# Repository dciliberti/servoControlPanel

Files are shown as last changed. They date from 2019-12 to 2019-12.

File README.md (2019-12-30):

# servoControlPanel
A panel to control a servo rotation and read angle on a LCD display, with the possibility to set a reference angle and read values from that reference. Useful to get the deflection angle of a control surface from a datum. Once set a reference angle, to get again the absolute position of the servo, just reset the Arduino. There is also the possibility to perform an automatic sweep between two given angles, from a given reference, and to change the rotational speed of the servo, by adjusting the delay between successive angles.

## Task
The idea is to realize an instrument panel to control a servo and display the angle and sweep mode on a LCD screen. Although compact and cheap boards dedicated to servo testing do exist, I wanted to realize a device to control and display the flap deflection of a wing model in a little, didactic wind tunnel and I wanted to do it, as far as possible, with the items provided in the [Arduino Starter Kit](https://store.arduino.cc/genuino-starter-kit).

## Requirements
Usually, servo testers give the possibility to control the servo angle by rotating a knob, put the servo in the neutral position, and sweep automatically between the minimum and maximum angle positions. Since my objective is to provide a user interface for wing angle of attack variation or control surface deflection, I do not need to put the servo in the neutral position (i.e. 90° if the servo rotates between 0° and 180°), but I need a switch to set a reference zero angle. In fact, the servo may be at any position while the wing (or control surface) angle relative to the wind is null. Also, I am interested to measure the deflection of the control surface relative to the reference zero. Finally, I want the servo to automatically sweep between two given angles around the reference zero at a certain angular velocity, which I want to control, although I am not interested in measuring it (I just want it to rotate faster or slower).

## Usage
The panel operates in two modes: manual control and auto sweep. The user interface provides three buttons, a knob, and a LCD screen. The display shows the servo angle in manual control mode and the limit angles (set in the Arduino code and not editable from the panel) in auto- sweep mode. The switch buttons serve as zeroing the reference angle, commuting between the manual control and auto-sweep mode, and changes the sign of the angle reported on the LCD display. In fact, since the servo rotation may be opposite to the desired convention, the last switch button gives the possibility to change the sign on the screen, but does not invert the rotation of the servo, which is linked to the rotation of the knob. In manual control mode, the servo knob controls the servo angle, which is shown on the LCD screen. Initially, the display shows the servo absolute angle, after the zeroing it shows the servo angle relative to that zero. In the auto-sweep mode, the servo knob controls the rotation rate by adjusting the delay between consecutive rotations (between 15 and 100 ms). By default, the auto-sweep mode rotates the servo in the range -30° to +60° from the reference zero value. The program limits the servo rotation if the reference zero plus the sweep range run out of the limits (0-179).

## Final considerations
I have managed to use items from the Arduino Starter Kit except for the bigger breadboard. Consider that you may need an external power source to control the servo, according to the voltage and power consumption of your device. If the servo vibrates, check your connections, then try to add an external power source. You may need to rearrange some of the items on your breadboard with respect to what is shown on my pictures. Additional information and pictures are available in the [docs folder](docs/).

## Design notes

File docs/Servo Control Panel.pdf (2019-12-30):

## Servo Control Panel

The idea is to realize an instrument panel to control a servo and display the angle and sweep mode on a LCD screen. Although compact and cheap boards dedicated to servo testing do exist, I wanted to realize a device to control and display the flap deflection of a wing model in a little, didactic wind tunnel and I wanted to do it, as far as possible, with the items provided in the Arduino Starter Kit. Usually, servo testers give the possibility to control the servo angle by rotating a knob, put the servo in the neutral position, and sweep automatically between the minimum and maximum angle positions. Since my objective is to provide a user interface for wing angle of attack variation or control surface deflection (Fig. 1), I do not need to put the servo in the neutral position (i.e. 90° if the servo rotates between 0° and 180°), but I need a switch to set a reference zero angle. In fact, the servo may be at any position while the wing (or control surface) angle relative to the wind is null. Also, I am interested to measure the deflection of the control surface relative to the reference zero. Finally, I want the servo to automatically sweep between two given angles around the reference zero at a certain angular velocity, which I want to control, although I am not interested in measuring it (I just want it to rotate faster or slower).

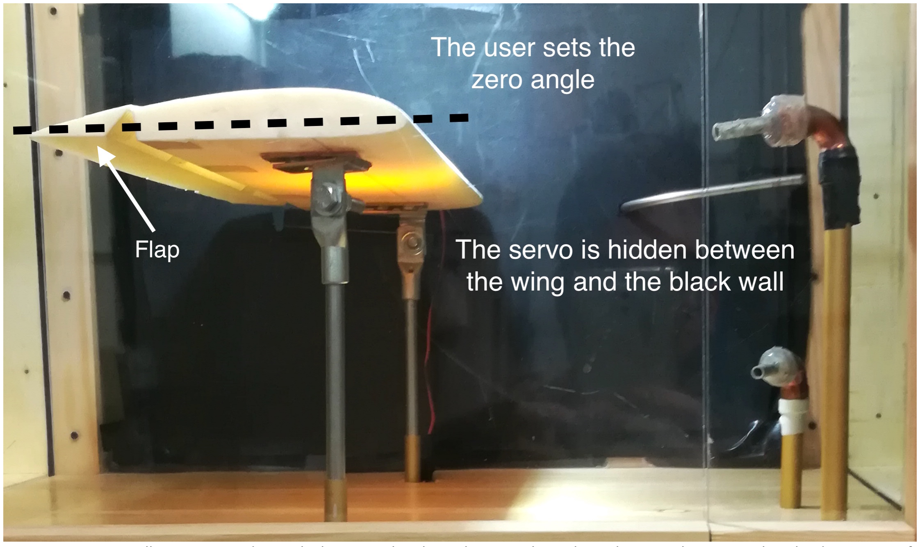
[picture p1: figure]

Fig. 1 – A wing installation in a wind tunnel. This tutorial is about the control panel not shown in this picture, but the description of the apparatus explains the motivations of the control panel functionality.

In my case, I used a little servo with JR connector, I assumed that the flap angle is equal to the servo angle (this is a rough estimate), and the auto-sweep function has been set between -30° and +60° (positive values, means increase in lift force: flap rotates down, the aerodynamic force increases upwards.
The panel operates in two modes: manual control and auto sweep. The user interface provides three buttons, a knob, and a LCD screen. The display shows the servo angle in manual control mode and the limit angles (set in the Arduino code and not editable from the panel) in autosweep mode. The switch buttons serve as zeroing the reference angle, commuting between the manual control and auto-sweep mode, and changes the sign of the angle reported on the LCD display. In fact, since the servo rotation may be opposite to the desired convention, the last switch button gives the possibility to change the sign on the screen, but does not invert the rotation of the servo, which is linked to the rotation of the knob. In manual control mode, the servo knob controls the servo angle, which is shown on the LCD screen. Initially, the display shows the servo absolute angle, after the zeroing it shows the servo angle relative to that zero. In the auto-sweep mode, the servo knob controls the rotation rate by adjusting the delay between consecutive rotations (between 15 and 100 ms). Breadboard connections and interactive actions are shown in Fig. 2.

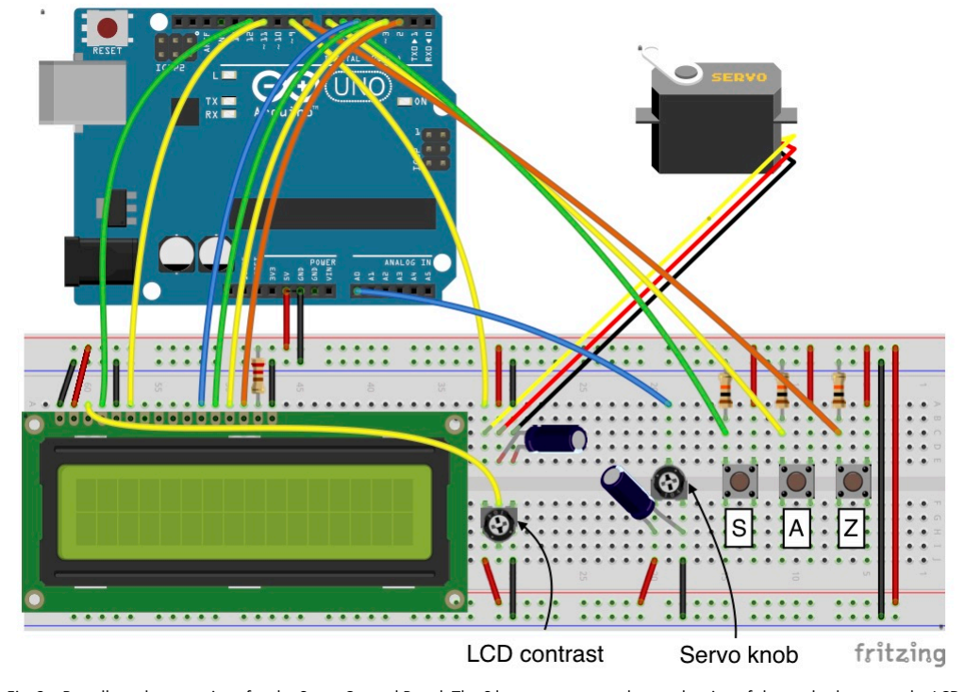
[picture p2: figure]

Fig. 2 – Breadboard connections for the Servo Control Panel. The S button serves to change the sign of the angle shown on the LCD screen. The A button commutes between manual control and auto-sweep. The Z button set the actual servo angle as zero. The servo knob controls the servo angle in manual mode and rotation rate in auto-sweep mode.
I have managed to use items from the Arduino Starter Kit except for the bigger breadboard. The panel shown in Fig. 3 has a slightly different arrangement from the breadboard view of Fig. 2 for assembly reasons. Consider that you may need an external power source to control the servo, according to the voltage and power consumption of your device. If the servo vibrates, check your connections, then try to add an external power source. You may need to rearrange some of the items on your breadboard.

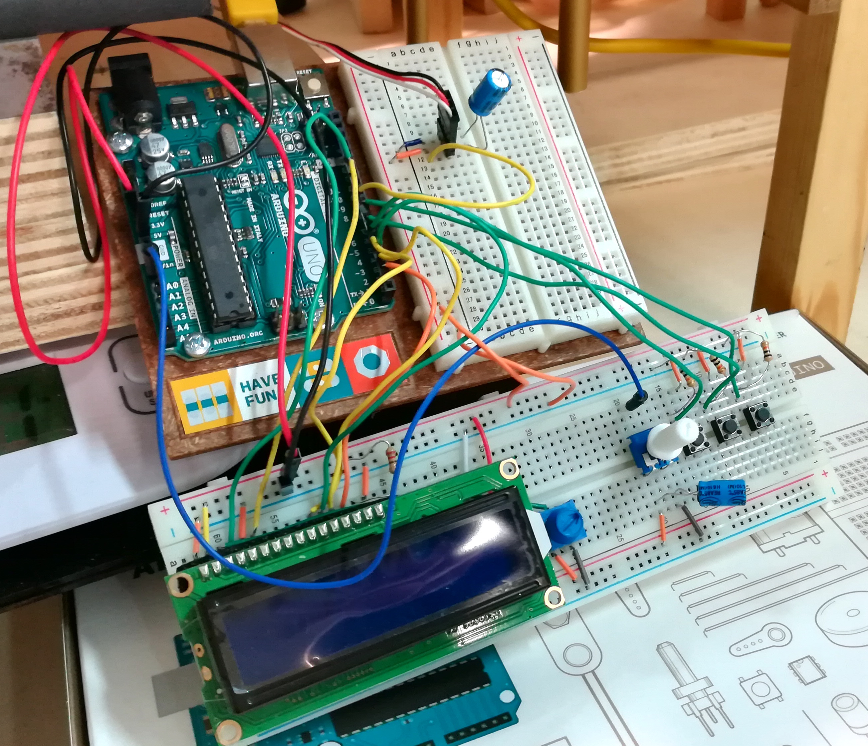
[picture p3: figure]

Fig. 3 – My arrangement of the Servo Control Panel.

Note: although incorrect, I have kept the original names for the code filename, variables, and display statements. Angle of attack, alpha, AOA are synonymous, defined as the angle between a reference line and the wind direction in the longitudinal plane. In my application, I have changed the deflection angle of a control surface, which also changes the angle of attack, by altering the local wind direction due to the pressure difference between the upper and lower wing surfaces. By AOA on the display I mean servo angular position, which is related to the control surface deflection by the linkage system. The variation of angle of attack and lift force due the control surface deflection is related to the control surface effectiveness.

## Bill of Materials: angleAttackControlPanel.fzz

/Users/danilo/Documents/Arduino/angleAttackControlPanel/angleAttackControlPanel.fzz

sabato, dicembre 9 2017, 11:53:40
Assembly List
Label | Part Type | Properties
Arduino UNO | Arduino Uno
| (Rev3) | tipo Arduino UNO (Rev3)
Autosweep
ON/OFF Switch | Pushbutton | package [THT]
Autosweep Switch
Pulldown | 10kΩ Resistor | tolerance ±5%; package THT; bands 4; resistenza 10kΩ; pin spacing 400 mil
LCD | LCD screen | tipo Character; pins 16
LCD Contrast Knob Trimmer
| Potentiometer | tipo Trimmer Potentiometer; package THT; maximum resistance 10kΩ; size Trimmer - 12mm; track Linear
R1 | 220Ω Resistor | tolerance ±5%; package THT; bands 4; resistenza 220Ω; pin spacing 400 mil
Servo | Basic Servo
Servo Angle Knob Trimmer
| Potentiometer | tipo Trimmer Potentiometer; package THT; maximum resistance 10kΩ; size Trimmer - 12mm; track Linear

Servo Capacitor1 Electrolytic

| Capacitor | package 100 mil [THT, electrolytic]; capacitance 100µF; voltage 6.3V
Servo Knob Capacitor | Electrolytic Capacitor | package 100 mil [THT, electrolytic]; capacitance 100µF; voltage 6.3V
Sign Switch | Pushbutton | package [THT]
Sign Switch
Pulldown | 10kΩ Resistor | tolerance ±5%; package THT; bands 4; resistenza 10kΩ; pin spacing 400 mil
Zero Switch | Pushbutton | package [THT]
Zero Switch
Pulldown | 10kΩ Resistor | tolerance ±5%; package THT; bands 4; resistenza 10kΩ;
pin spacing 400 mil
Shopping List
Amount | Part Type | Properties
1 | Arduino Uno (Rev3) tipo Arduino UNO (Rev3)
3 | Pushbutton | package [THT]
3 | 10kΩ Resistor | tolerance ±5%; package THT; bands 4; resistenza 10kΩ; pin spacing
400 mil
1 | LCD screen | tipo Character; pins 16
2 | Trimmer
Potentiometer

tipo Trimmer Potentiometer; package THT; maximum resistance 10kΩ; size Trimmer - 12mm; track Linear
1 | 220Ω Resistor | tolerance ±5%; package THT; bands 4; resistenza 220Ω; pin spacing
400 mil

Amount | Part Type | Properties
1 | Basic Servo
2 | Electrolytic
| Capacitor | package 100 mil [THT, electrolytic]; capacitance 100µF; voltage 6.3V

Exported with Fritzing 0.9.3- http://fritzing.org

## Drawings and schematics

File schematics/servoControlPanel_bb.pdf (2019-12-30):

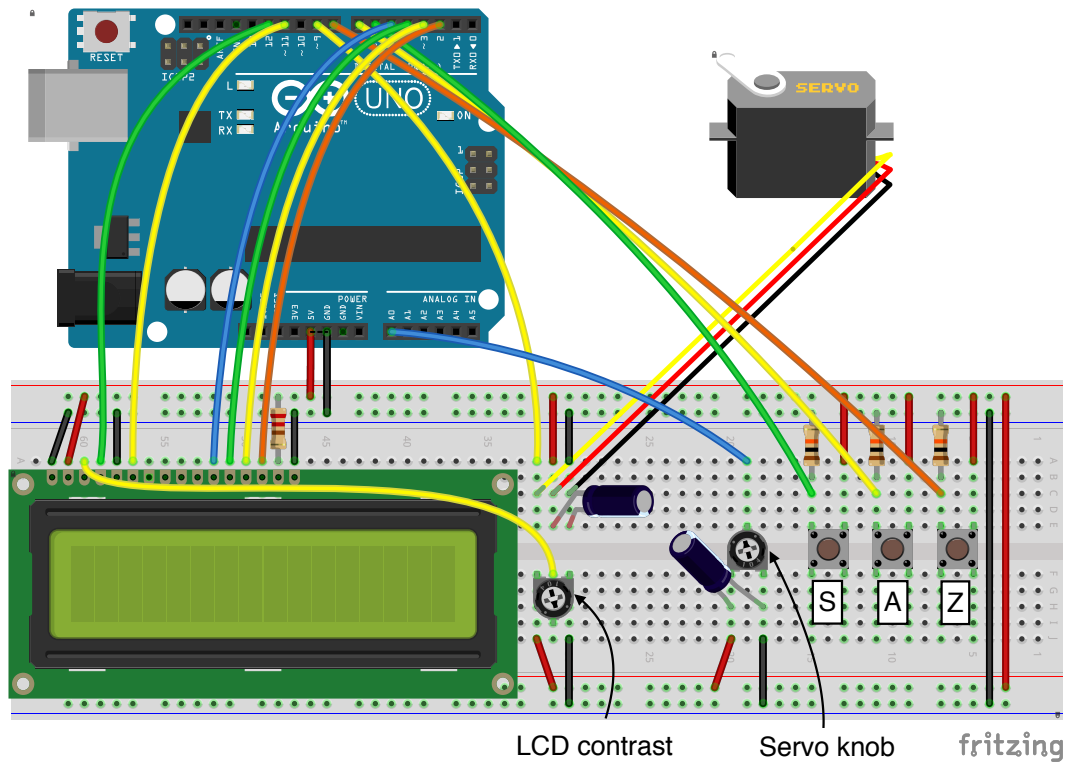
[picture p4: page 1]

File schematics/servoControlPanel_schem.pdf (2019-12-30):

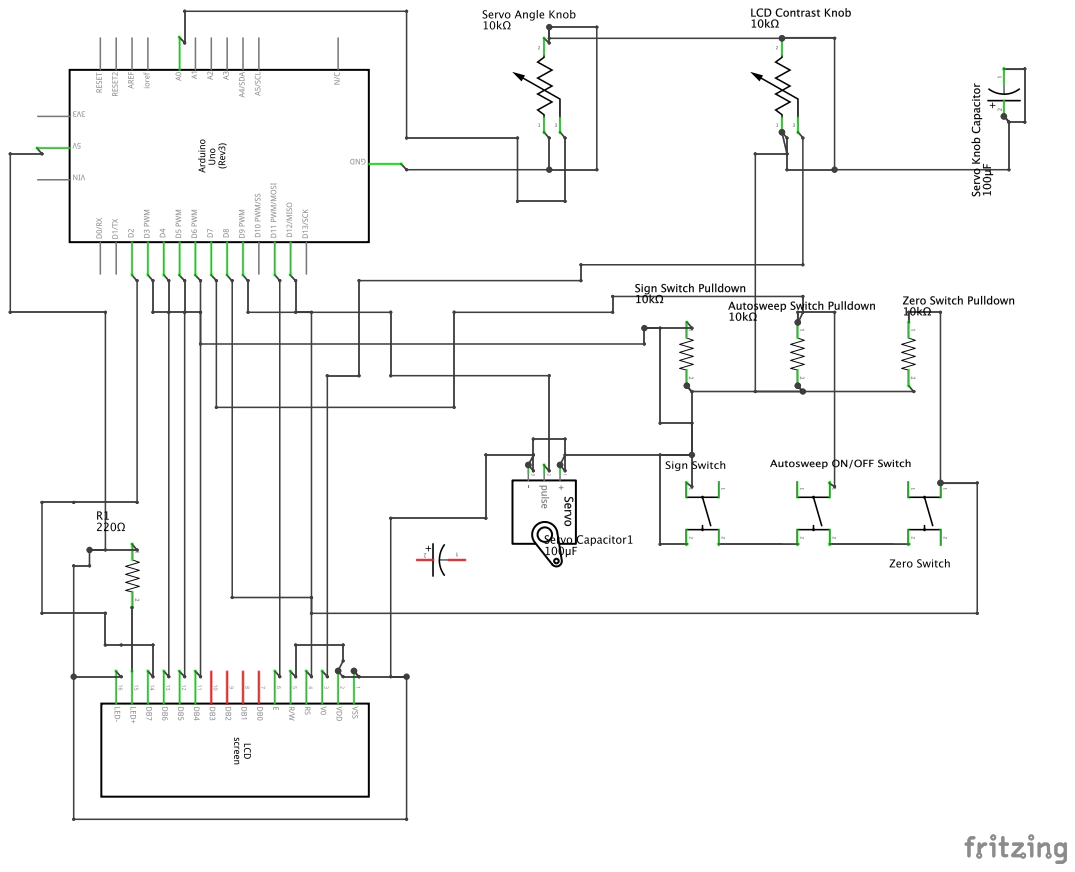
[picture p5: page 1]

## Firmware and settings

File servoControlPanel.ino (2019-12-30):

/************************************************************************
    Panel to control a servo rotation and read angle on a LCD display,
    with the possibility to set a reference angle and read values
    from that reference. Useful to get the deflection angle of a 
    control surface from a datum. Once set a reference angle, to get
    again the absolute position of the servo, just reset the Arduino.
    There is also the possibility to perform an automatic sweep
    between two given angles, from a given reference, and to change
    the rotational speed of the servo, by adjusting the delay between
    successive angles.

    Copyright (C) 2017 Danilo Ciliberti dancili@gmail.com
    This program is free software: you can redistribute it and/or modify
    it under the terms of the GNU General Public License as published by
    the Free Software Foundation, either version 3 of the License, or
    (at your option) any later version.
    This program is distributed in the hope that it will be useful,
    but WITHOUT ANY WARRANTY; without even the implied warranty of
    MERCHANTABILITY or FITNESS FOR A PARTICULAR PURPOSE.  See the
    GNU General Public License for more details.
    You should have received a copy of the GNU General Public License
    along with this program. If not, see <https://www.gnu.org/licenses/>
*************************************************************************/    

#include <LiquidCrystal.h>
#include <Servo.h>
LiquidCrystal lcd(12, 11, 5, 4, 3, 2);
Servo myServo;

int const signPin = 6;  // button to switch sign of the angle
int const sweepPin = 7; // button to turn auto angle sweep on/off
int const zeroPin = 8;  // button to set reference
int const pot = A0;     // potentiometer that controls angle/rate
int potVal;             // value of the angle/rate
int angle;              // angle of the servo
int rotDelay;           // speed of the servo (delay between angles)
int zero = 0;           // reference angle of attack
int signSwitch = 1;     // sign of the angle (positive or negative)
int alpha;              // angle of attack
int sweepState = 0;     // auto sweep state (on/off)
int lowLimit = -30;     // low angle limit for auto sweep
int highLimit = 60;     // high angle limit for auto sweep
int newLowLimit;        // low limit angle from the zero
int newHighLimit;       // high limit angle from the zero

void setup() {
  pinMode(zeroPin, INPUT);
  pinMode(signPin, INPUT);

  lcd.begin(16, 2);
  lcd.print("Angle of attack");
  lcd.setCursor(0, 1);
  lcd.print("control panel");
  delay(3000);
  lcd.clear();

  myServo.attach(9);  // servo is attached to pin 9
  Serial.begin(9600);
}

void loop() {

  // if the zero button is pressed the angle of attack is set to 0
  if (digitalRead(zeroPin) == HIGH) {
    zero = angle;
    // centers the auto sweep limits around the new zero
    newLowLimit = lowLimit + zero;
    newHighLimit = highLimit + zero;
    Serial.print("Setting low angle limit: ");
    Serial.println(newLowLimit);
    Serial.print("Setting high angle limit: ");
    Serial.println(newHighLimit);
    delay(100);
  }

  // if the sign button is pressed changes the sign of the angle
  if (digitalRead(signPin) == HIGH) {
    signSwitch = -1 * signSwitch;
    delay(100);
  }

  alpha = signSwitch * (angle - zero);   // angle of attack respect to reference

  // check if auto sweep button has been pressed
  if (digitalRead(sweepPin) == HIGH) {
    sweepState = 1;
    Serial.print("Auto sweep state = ");
    Serial.println(sweepState);
    lcd.clear();
    delay(100);
  }

  // turn on auto sweep if auto sweep button has been pressed
  if (sweepState == 1) {

    // check if alpha range is out of servo range
    if (newLowLimit < 0 || newLowLimit > 179) {
      newLowLimit = 0;
      Serial.print("Actual low angle limit: ");
      Serial.println(newLowLimit);
    }
    if (newHighLimit > 179 || newHighLimit < 0) {
      newHighLimit = 179;
      Serial.print("Actual high angle limit: ");
      Serial.println(newHighLimit);
    }
    
    // if auto sweep button has been released
    if (digitalRead(sweepPin) == LOW) {
      
      lcd.home();
      lcd.print(lowLimit);
      lcd.print(" < AOA < ");
      lcd.print(highLimit);
      lcd.setCursor(0, 1);
      lcd.print("Auto sweep ON");

      // check the angle sign to assign correct sweep angles sequence
      if (signSwitch == 1) {
        angle = zero + alpha;
      }
      else {
        angle = zero - alpha;
        newHighLimit = -lowLimit + zero;
        newLowLimit = -highLimit + zero;
      }

      while (angle < newHighLimit) {
        // assign delay between angles, varying servo rotational speed
        potVal = analogRead(pot);
        Serial.print("potVal: ");
        Serial.print(potVal);
        rotDelay = map(potVal, 0, 1023, 15, 100);
        Serial.print(", rotDelay: ");
        Serial.print(rotDelay);
        Serial.println(" ms");
        myServo.write(angle);
        delay(rotDelay);
        
        // if during loop auto sweep button is pressed exit the loop
        if (digitalRead(sweepPin) == HIGH) {
          sweepState = 0;
          Serial.print("Auto sweep state = ");
          Serial.println(sweepState);
          lcd.clear();
          delay(100);
          goto manual;
        }
        angle++;
      }
      
      while (angle > newLowLimit) {
        // assign delay between angles, varying servo rotational speed
        potVal = analogRead(pot);
        Serial.print("potVal: ");
        Serial.print(potVal);
        rotDelay = map(potVal, 0, 1023, 15, 100);
        Serial.print(", rotDelay: ");
        Serial.print(rotDelay);
        Serial.println(" ms");
        myServo.write(angle);
        delay(rotDelay);
        
        // if during loop auto sweep button is pressed exit the loop
        if (digitalRead(sweepPin) == HIGH) {
          sweepState = 0;
          Serial.print("Auto sweep state = ");
          Serial.println(sweepState);
          lcd.clear();
          delay(100);
          goto manual;
        }
        angle--;
      }
      
    }
  }
  else {  // if auto sweep is turned off
    manual:   // label destination of interrupted loop
    lcd.setCursor(0, 1);
    lcd.print("Manual control");
    
    potVal = analogRead(pot);
    Serial.print("potVal: ");
    Serial.print(potVal);
    angle = map(potVal, 0, 1023, 0, 179);
    Serial.print(", angle: ");
    Serial.print(angle);
    myServo.write(angle);
    delay(15);
    Serial.print(", zero: ");
    Serial.print(zero);
    Serial.print(", AOA: ");
    Serial.println(alpha);
    
    lcd.home();
    lcd.print("AOA = ");
    // To avoid overlapping text among readings I must use blank 
    // characters (space) when needed over the four predicted positions.
    
    // between -179 and -100 four digits are assigned
    if (alpha >= -179 && alpha <= -100) {
      lcd.print(alpha);
      lcd.print(" deg");  // no space after
    }
    // between -99 and -10 three digits are assigned
    else if (alpha >= -99 && alpha <= -10) {
      lcd.print(alpha);
      lcd.print(" deg ");  // one space after
    }
    // between -9 and -1 two digits are assigned
    else if (alpha >= -9 && alpha <= -1) {
      lcd.print(alpha);
      lcd.print(" deg  ");  // two spaces after
    }
    // between 0 and 9 only one digit is assigned
    else if (alpha >= 0 && alpha <= 9) {
      lcd.print(alpha);
      lcd.print(" deg   ");  // three spaces after
    }
    // between 10 and 99 two digits are assigned
    else if (alpha >= 10 && alpha <= 99) {
      lcd.print(alpha);
      lcd.print(" deg  ");  // two spaces after
    }
    // between 100 and 179 three digits are assigned
    else if (alpha >= 100 && alpha <= 179) {
      lcd.print(alpha);
      lcd.print(" deg ");  // one spaces after
    }
    // out of -179,+179 the servo cannot rotate
    else {
      lcd.home();
      lcd.print("Error: signal");
      lcd.setCursor(0,1);
      lcd.print("out of range.");
      delay(1000);
      lcd.clear();
    }
  }
}
